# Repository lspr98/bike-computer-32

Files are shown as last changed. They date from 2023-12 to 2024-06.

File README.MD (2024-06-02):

# ESP32-based mini-map for biking

A simple mini-map based on an ESP32C3 for cycling. Renders a map based on the current position and optionally overlays a GPX-track. Featuring OSM-based offline maps with multi-constellation GNSS-positioning and GPX-track rendering.

**DISCLAIMER:** This is a hobby project which lacks documentation, clean code and unit tests.

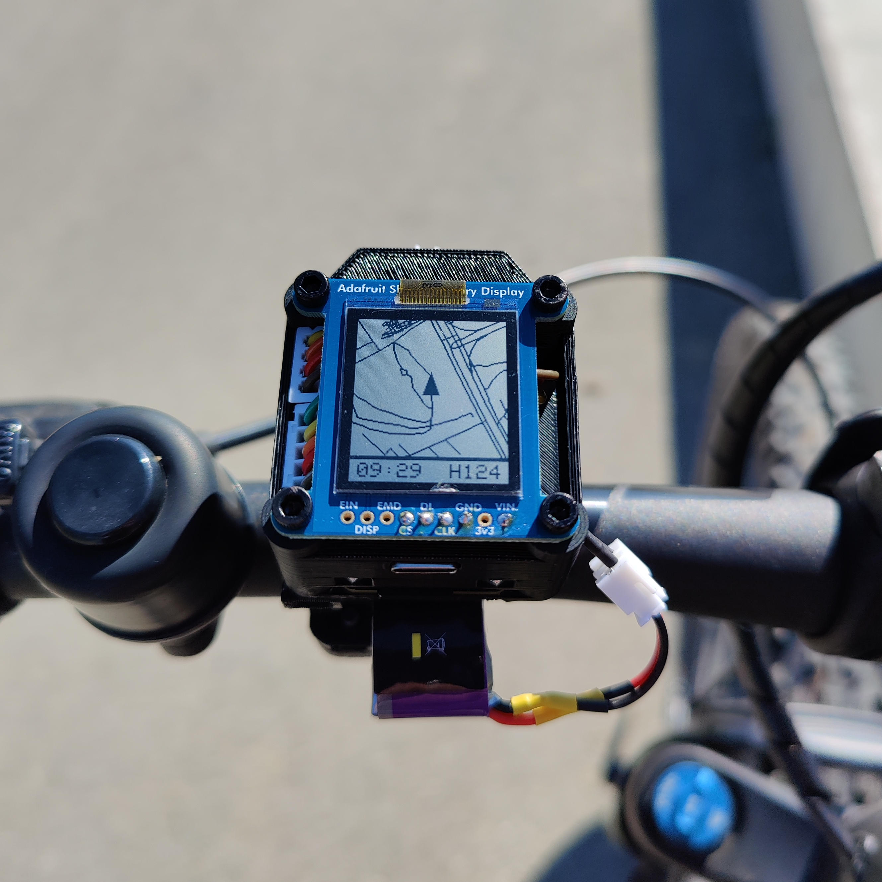
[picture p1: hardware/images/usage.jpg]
 


Even though the GIF is low-framerate, the ESP can easily render the map at 60 FPS if the currently shown part of the map isn't too busy.

The motivation behind this project was to create a cheap (~50€) device that displays a komoot gpx track as an overlay over a map for cycling. It has to work without a smartphone, be readable in direct sunlight and last a couple of hours in terms of battery.

## Project structure
```
hardware            Contains instructions/sources/files to build the physical device
software            Software to convert maps, view exported maps and the embedded code for the ESP
software/cpp        Tool to convert OSM maps to an optimized format for the ESP
software/python     Utilities to inspect converted maps and/or get familiar with the map layout
software/esp32      Firmware for the ESP32
```

## Building instructions
### Building the hardware
A wiring diagram, sourcing-list and a .STEP file of the whole assembly can be found in the **hardware** folder. Please refer to the STEP file for assembling the device.

For the 3D-Printed parts (**hardware/STL**), I recommend the following print settings:
|Settings|Value|
|---|---|
|Wall count|4|
|Top/Bottom Layers|4|
|Layer Height|0.2mm|
|Material|ABS/ASA|
|Infill|40%|
|Support|Yes|

My device is printed out of PLA+ but ASA/ABS is the better choice for this application.

### Creating a map
Follow the instructions in **software/cpp/README.MD** to compile the conversion tool and create a map binary.

### Preparing the SD-Card
1. Format the SD-Card as FAT32.
2. Place the map as **map.bin** in the root folder of the SD-Card
3. (Optional) Place the GPX-track as **track.gpx** in the root folder of the SD-Card

### Flashing the firmware
1. Install Visual Studio Code
2. Install the Platform.io extension for Visual Studio Code
3. Open the Platform.io project **software/esp32/esp32c3-bike-companion-32**
4. Have a look at the **main.cpp**. You may need to fix a bug in one of the libraries for the SDCard-Reader.
5. Connect your Seeed ESP32C3 to your PC
6. Flash the firmware

## Usage
All you need to do is mount the device to your bike and connect it to a power source.

The device will automatically power on. It does a small self check on boot and then enters fixing mode, where it remains until it receives a valid position fix from the GNSS module. The map with the current position is only rendered if there is a valid position fix, otherwise it will show "Fixing...".

## Troubleshooting
If the device encounters an issue during boot (e.g. one component shows **ER**), check the serial monitor for log messages.

## CAD Credits
The 3D-models for the ESP32C3 are from GrabCAD:

|Model|Author|Link|
|---|---|---|
|ESP32C3|[Maurice Pannard](https://grabcad.com/maurice.pannard-1)|[Source](https://grabcad.com/library/seeed-studio-xiao-esp32-c3-1)|

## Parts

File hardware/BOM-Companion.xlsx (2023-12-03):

Category | Description | Quantity | Price (€) | Sourcing
Fasteners | M2.5 x 8 FHCS | 2 | 0 | Local Hardware-Store / Screw Sortiment
 | M2.5 Nut | 2 | 0 | Local Hardware-Store / Screw Sortiment
 | M3 x 10 SHCS | 2 | 0 | Local Hardware-Store / Screw Sortiment
 | M3 x 30 SHCS | 4 | 0 | Local Hardware-Store / Screw Sortiment
 | M3 Nut | 6 | 0 | Local Hardware-Store / Screw Sortiment
Electronics | Seeed Xiao ESP32C3 | 1 | 4.55 | https://www.digikey.de/de/products/detail/seeed-technology-co-ltd/113991054/16652880
 | Adafruit Micro SD SPI/SDIO Card Breakout Board (Product ID: 4682) | 1 | 3.19 | https://www.digikey.de/de/products/detail/adafruit-industries-llc/4682/12822319
 | Adafruit SHARP Memory Display 1.3" 168x144 Monochrome (Product ID: 3502) | 1 | 22.75 | https://www.digikey.de/de/products/detail/adafruit-industries-llc/3502/7386264
 | Quectel L86-M33 | 1 | 11.38 | https://www.digikey.de/de/products/detail/quectel/L86-M33/13278361
 | MicroSD-Card | 1 | 5 | Electronics-Store / Amazon
 | LiPo 1s Battery 3.8V (Tiny-Whoop Battery) | 1 | 10 | Hobby-Shop / Amazon
 | Wires | ~1 meter | 0
 | Solder / Heatshrinks |  | 0
 | Plugs to connect components (optional) |  | 0
Misc | 3D-Printing Filament | ~50 gramms | 0
 | Double-Sided Tape |  | 0
Total |  |  | 56.87

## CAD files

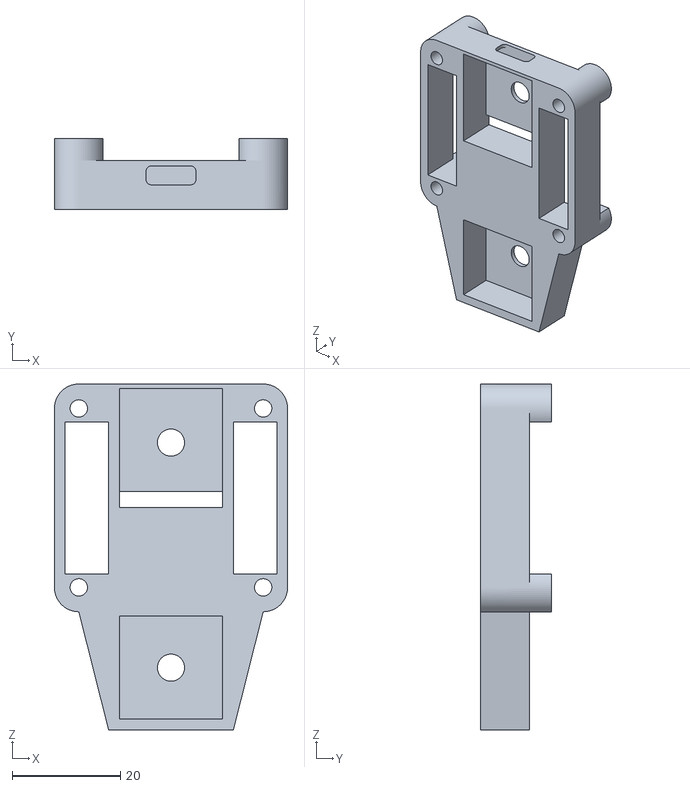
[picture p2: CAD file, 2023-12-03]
hardware/STL/MainFrameGNSSExposed v2.stl
43.0 x 13.0 x 63.8

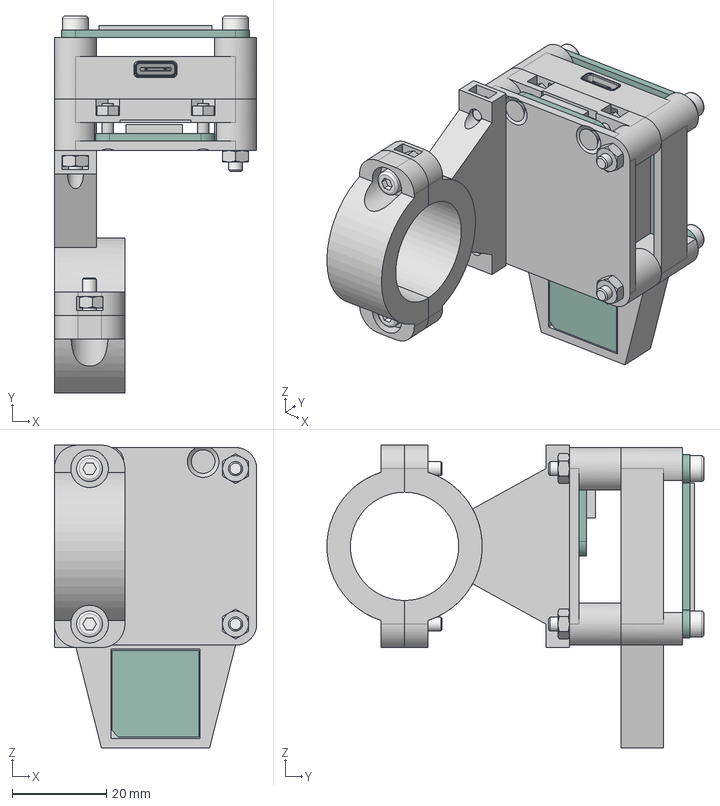
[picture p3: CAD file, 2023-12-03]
hardware/STEP/Bike-Companion-32.step
43.0 x 80.1 x 64.3 mm
M3x30 Screw x 4
M2_5x8 Screw x 2
M3x10 Screw x 2
Adafruit Sharp Memory Display
Adafruit SD-Card Reader
BOSS-EXTRUDE14_8_
BOSS-EXTRUDE7_4_
BOSS-EXTRUDE7_3_
BOSS-EXTRUDE14_4_
BOSS-EXTRUDE14_2_
BOSS-EXTRUDE14_11_
BOSS-EXTRUDE7_7_
BOSS-EXTRUDE14_9_
BOSS-EXTRUDE14_3_
BOSS-EXTRUDE14_7_
MIRROR2
BOSS-EXTRUDE14_5_
BOSS-EXTRUDE14_12_
BOSS-EXTRUDE7_8_
BOSS-EXTRUDE7_1_
BOSS-EXTRUDE14_10_
BOSS-EXTRUDE7_9_
BOSS-EXTRUDE14_6_
BOSS-EXTRUDE14_1_
BOSS-EXTRUDE7_6_
BOSS-EXTRUDE7_2_
CUT-EXTRUDE5
BOSS-EXTRUDE7_5_
U.FL Connector v1
Button (1) x 2
Shield
Quectel-L86
M2 Nut x 2
M3 Nut x 6
MainFrameGNSSExposed
BottomFrame
BikeMountUpper
BikeMountLower

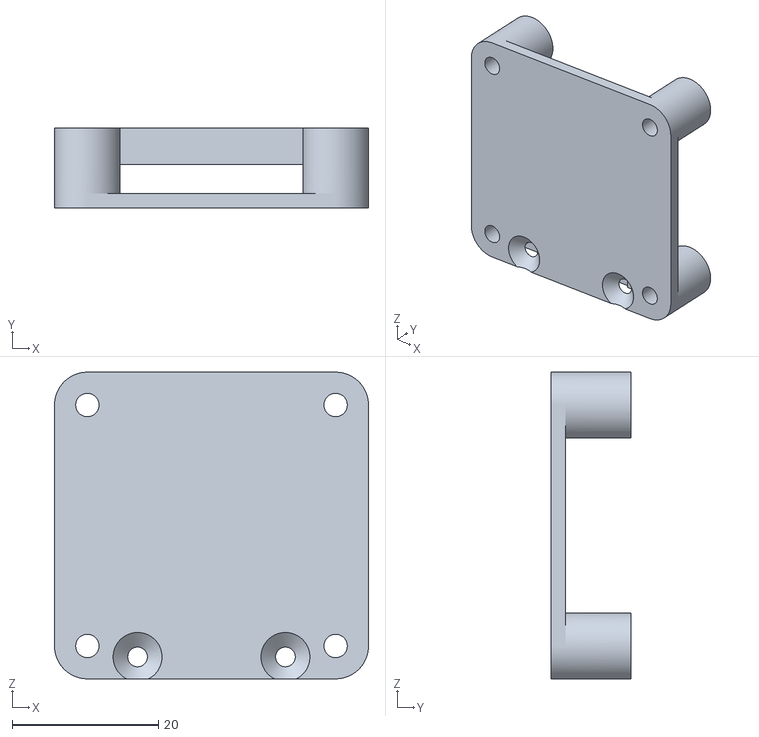
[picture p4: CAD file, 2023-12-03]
hardware/STL/BottomFrame v4.stl
43.0 x 11.0 x 42.0

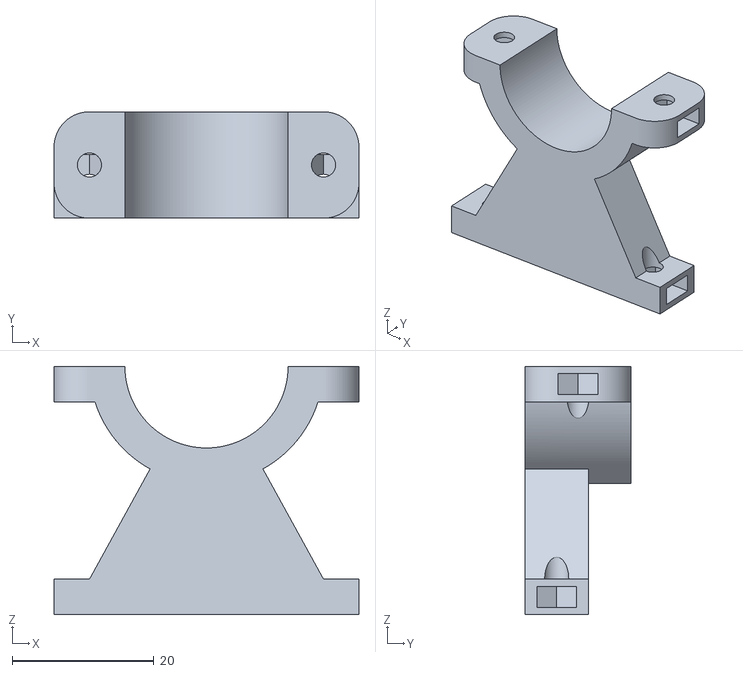
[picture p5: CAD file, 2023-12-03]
hardware/STL/BikeMountUpper v2.stl
43.0 x 15.0 x 35.0

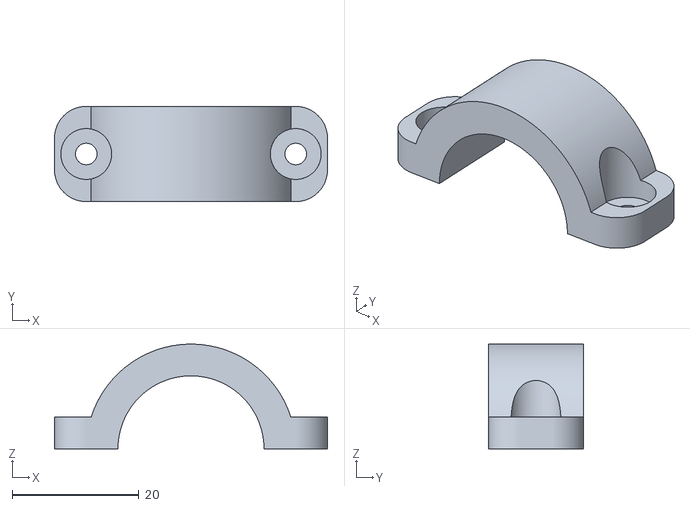
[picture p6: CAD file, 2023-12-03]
hardware/STL/BikeMountLower v1.stl
43.0 x 15.0 x 16.5

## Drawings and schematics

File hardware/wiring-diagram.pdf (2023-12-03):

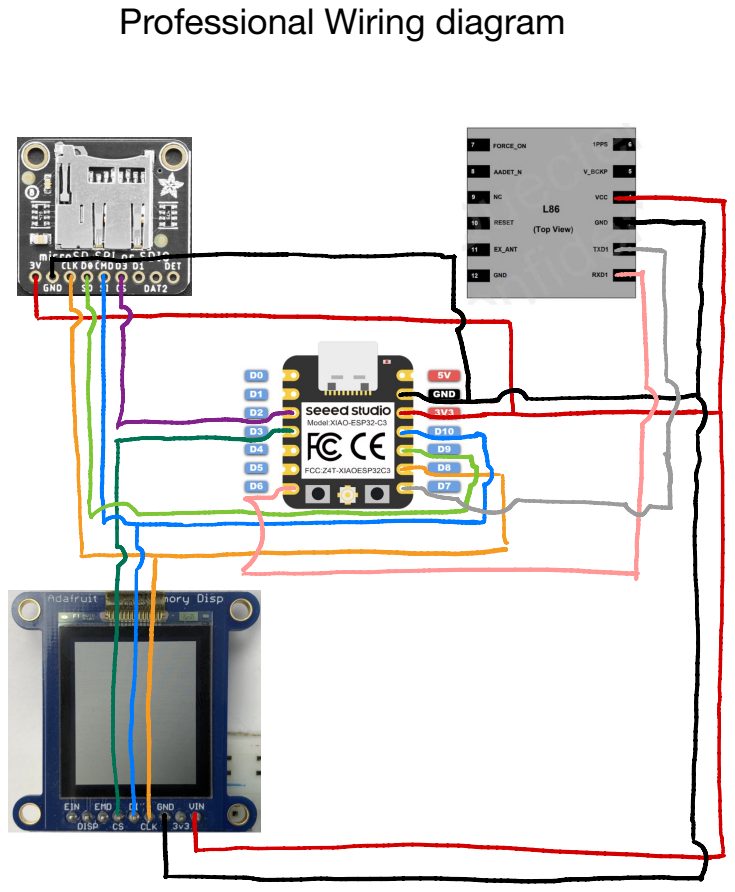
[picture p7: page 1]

Professional Wiring diagram

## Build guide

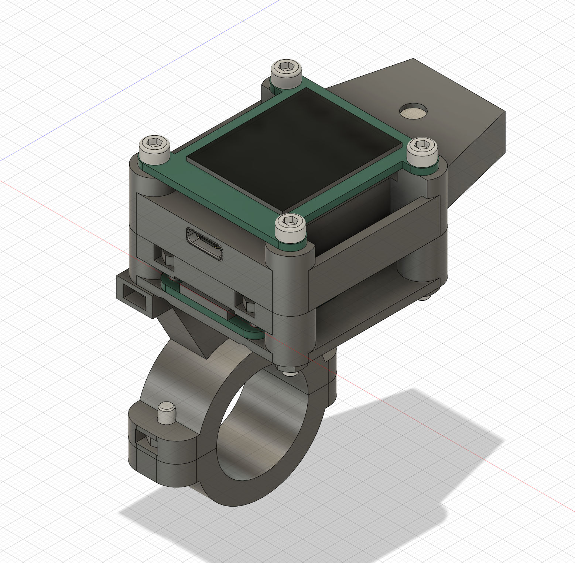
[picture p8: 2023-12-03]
hardware/images/assembly.jpg

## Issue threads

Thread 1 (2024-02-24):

Using an OLED display

korsehindi, 2024-02-24:
Hi,
The display used in this project is expensive and can't even be found in Chinese stores, how to use an 1.3 inch oled display with i2c connection.

lspr98, 2024-02-26:
Hey korsehindi,

the memory display was chosen due to its good readability in direct sunlight and low power consumption. Using an i2c display  (TFT, OLED, etc...) should be possible since the pins D4 and D5 are still unused but I cant guarantee it since I dont have any i2c displays to try it.

This repository provides some tests I wrote for the individual hardware components that you can adapt to make it work with your own display. Have a look at [software/esp32/esp32c3-display-test/src/main.cpp](https://github.com/lspr98/bike-computer-32/blob/main/software/esp32/esp32c3-display-test/src/main.cpp). The test renders a small part of a map to the display and rotates it indefinitely around the center. If you can use your display with the Adafruit GFX library, then it should be relatively straight forward to replace the display.* calls with the equivalent for your display.

Once that works, you can have a try at adapting [software/esp32/esp32c3-bike-companion-32/src/sharedspisdcard.cpp](https://github.com/lspr98/bike-computer-32/blob/main/software/esp32/esp32c3-bike-companion-32/src/sharedspidisplay.cpp) to your display but you will be on your own for that.

korsehindi, 2024-02-28:
Thanks, I will try, I hope I succeed.
I will probably need your help.

iDoka, 2024-04-02:
+1

Would be nice to have an alternative (and cheaper) display which can order on Aliexpress with at least several different suppliers.

If anybody know cheap E-Ink display with similar dimension - please share (sunlight is a huge issue in my geo).

idreamsi, 2024-04-02:
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

There is an alternative (and cheaper).
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

more info: [+](http://www.technoblogy.com/show?3YB0) , [+](https://www.aliexpress.com/item/1005003654720684.html)

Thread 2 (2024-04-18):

Segmentatio fault

cayleyflyer, 2024-04-18:
HI
Many thanks for sharing your code
I have compiled the code using cmake which all went well ,  but when i run it  "./osm2simpletile east.pbf  mapeast.bin"
it runs through process 1/6 and 2/6 and stops at 3/6

I get a segmentation fault at 3/6

**------------------------- 3/6 Mapping highways to tiles ------------------------
Segmentation fault (core dumped**)

I got the fault on my lap top which has 8mb of ram and also on my desktop machine. which is also running Ubuntu 22.04, with 32mb of ram. Any suggestions would be appreciated.
regards
jez

lspr98, 2024-04-19:
Hey jez,

I supposed you mean 8gb (or 32gb) of ram? Anyway, the segmentation fault is probably not due to insufficient RAM but rather a bug on my side. To help you, I would need two things from you:

1. Could you try it with a .osm.pbf file from [geofabrik](https://download.geofabrik.de/) ? Maybe they even offer the map that you are interested in. This is where I get my maps from and for example the [germany.osm.pbf](https://download.geofabrik.de/europe/germany-latest.osm.pbf) map conversion works fine for me.

2. Where did you get east.pbf from? I'd like to try it with your file too to see if I can reproduce the issue.

cayleyflyer, 2024-04-19:
HI,
Thank you for your reply ,

Yes sorry, 8gb on laptop 32gb on desktop!

And yes I got my map from geofabrik .The file is in England named "east-yorkshire-with-hull-latest.osm.pbf" i just shortened it to 'east.pbf'  so i did not have to keep typing a long name.

OK I ran a .pbf file from geofabrik  named "bremen-latest.osm.pbf" and it worked  OK and created a bin file . I downloaded a freash   "east-yorkshire-with-hull-latest.osm.pbf"  and it gives the Segmentation fault as described.

With the above result my feeling is,  because '0' degrees longitude runs through England (and actually my town )in East Yorkshire. Everything to the East of me has a positive Longitude number  and everything West of my town has a negative longitude number. Therefore when  I run the  osm2simpletile  on a map that crosses '0' degrees longitude it gives A Segmentation error.

could this be the issue, the code handing negative longitude and positive longitude in the same file?

Kind regards
jez

lspr98, 2024-04-20:
Hey Jez,

thanks for the hint with 0 longitude. The problem was indeed caused by negative longitude coordinates. I have updated the conversion tool, the python utilities and the esp firmware to support signed coordinates. Could you please pull again and let me know if it works for you?

There is still one catch though: the map may not render portions of streets when near the 0 longitude and/or 0 latitude mark. I'm unsure if this is caused by a bug or a design choice I made to reserve negative local tile coordinates to encode meta data later on. You can use the jupyter notebook test_plot_partial_map.ipynb to check it out for yourself.

cayleyflyer, 2024-04-20:
HI,
Thank you
Whatever you did has solved the issue and now the OSM.pbf files that bisect '0' degrees lon,  compile to a .bin file OK.
For my flight instrument project I am aim to create a custom map showing Airspace restrictions with just main roads, railway lines and major landmarks, which can be seen from the air. so small streets will not be an issue.

many thanks for you help

Kind regards
Jez

Closed 2024-04-20.

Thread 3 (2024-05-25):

map scale

cayleyflyer, 2024-05-25:
Hi,
I am using a 400 x 240 Sharp Memory LCD. I am trying to fill the screen with a map to show a larger area. I can change the RENDER_TILES_PER_DIM = 7 and DETAULT_ZOOM_LEVEL = 0.1 (in Globalconfig.h). this produces a map of the scale close to what I wish to have (see pic)
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

The map however does not fill the screen,  and  7 appears to be the max number I can  use in RENDER_TILES_PER_DIM.  If I enter 9 or 11 for example it will not render the tiles. I thought it may be due to the tile renderer buffer size. I noted the buffer size in tileblockrederer.cpp (_renderTileData = new int16_t[_perTileBufferSize * N_RENDER_TILES])  was an int16_t so I changed it to a int32_t but this had no effect.

Have you any ideas that could allow me zoom out and fill the screen to see more area. For my project  I need to see at least 6km in front of my GPS position and 2km each side of my GPS position.

kind regards
Jeremy

lspr98, 2024-05-26:
Hey Jeremy,

my guess is that you are running out of RAM, which is why the map stops rendering if you go too high with **RENDER_TILES_PER_DIM**. From your picture, I see that you are using an ESP-WROOM-32, which comes with 520 kb of SRAM according to its datasheet. The size for **_renderTileData** is calculated based on the maximum number of nodes across all tiles in the map (**max_nodes** in header) and the number of tiles that are rendered (**N_RENDER_TILES**). The DACH map I am using has 4405 max_nodes, which means a 3 by 3 tile buffer requires 4405 * 2 * 3 * 3 ~ 80kb of RAM. A 7 by 7 buffer already requires ~431kb and a 9 by 9 buffer would require ~713kb, which exceeds that if your board. You can check the **max_nodes** value using the jupyter notebook **test_loading.ipynb** by printing the header dict after loading (in python, the value is called **max_tile_nodes**).

The simplest solution would be to upgrade to an ESP with more RAM, but I do not recommend that, since the computational complexity for rendering the map rapidly increases for a large amount of tiles. If you are moving fast, it will also constantly have to reload a lot of tiles from the SD-Card, which creates stutter.

As an alternative, you could change the **tile_size** in **main.cpp** of the map conversion tool to a higher value, say 1024 (or higher) instead of 512. This will have the same effect as zooming out with a factor of 2. A **DETAULT_ZOOM_LEVEL = 1.0** means that the tile matches the display width defined in **DISPLAY_WIDTH**. To resolve the RAM issue, you will have to refine the filter in the map conversion tool (search for all occurances of "highway" in **CustomHandlers.hpp**), to exclude smaller ways and only keep major highways, which will reduce the maximum number of nodes on the tiles. For the zoom level that you request (6 by 2 km map on a 400 x 240 screen) this shouldn't really be an issue.

Also note that **Globalconfig.h** has two constants **DISPLAY_WIDTH** and **DISPLAY_HEIGHT** that you will need to adapt.

Just out of curiosity, does it render across the full screen when you set **DETAULT_ZOOM_LEVEL = 1.0** with **RENDER_TILES_PER_DIM = 7** ? Maybe there is also another issue with different screen aspect ratios.

cayleyflyer, 2024-05-28:
Hi,
Thank you,
You detailed reply has made me better understand the code.

Yes the the map did render across the full sceen at Zoom level 1, however that map tile was size 513 nodes*2*7*7 = 50kb. My initial statergy was wrong, in trying to reduce the zoom size and increase the number of tiles to get the  6km x 4km view, as you have kindly explained in your reply. Increasing tile size will work.

After testing last night I created several maps at 1024,1800,1900,2048 tile size. I set zoom =1 and DIM = 3 .
max_nodes in each which gave 9kb,26kb,55,kb,64kb,72kb. However only maps upto (1800) 55kb loaded and displayed correctly. I will need a tile size 4096 to achieve the zoom level I need. With the ESP's 512kb of memory it should load with ease but mine does not. I have ordered a new ESP32 to rule out hardware issues, and I will make sure I have not mistakenly altered some code when adapting it to work without the shared SPI on the Wroom Board.

Again many thanks for your help
kind regards
Jeremy

thankyou for you help i am sure I will get

cayleyflyer, 2024-05-30:
A new ESP made no difference. So I kept the map tile size to 4096 in main.cpp and I filtered the large pbf file using OSMIUM to remove residential streets which reduced the max_nodes like this ,,,,, osmium tags-filter my.osm.pbf w/natural=water w/railway = rail w/railway=abandoned w/highway=motorway w/highway=trunk w/highway=primary w/highway=secondary w/highway=tertiary w/highway=unclassified  \-o reduced_node .pbf

This created a a map file  showing an area of 5.5km x 3.5km at zoom=1 and DIM=3 and kept the buffer to 38kb.
regards
Jeremy

lspr98, 2024-06-02:
Hey Jeremy,

sorry for the delay. I did some tests with my ESP and have to admit a mistake in the formula for calculating the necessary memory, there is a factor of 2 missing, since each node consists of two 16bit signed integers (which means 4 bytes per node are required). The **_renderTileData** buffer is initialized via heap initialization, so it is possible to check the memory before and afterwards via `ESP.getFreeHeap()`. Here is the header of the map I'm using as read by the jupyter notebooks provided:
```
{
'map_x': 652675,
'map_y': 5982838,
'map_width': 1027954,
'map_height': 1390019,
'n_x_tiles': 2008,
'tile_size': 512,
'n_tiles': 5451720,
'max_tile_nodes': 2871,
'total_tile_nodes': 104140822,
'ways': 64903320
}
```

Calling the method mentioned above allows you to print out the available heap memory for the buffer before and after buffer allocation. I wrote some debug messages to check how much memory is actually allocated:
```
maxNodes: 2871, nRenderTiles: 9, perTileBufferSize: 5742, sizeof(int16_t): 2
Free heap before _renderTileData allocation: 265564 bytes
_renderTileData size: 103356 bytes
Free heap after _renderTileData allocation: 162192 bytes
```
So **max_nodes** * **N_RENDER_TILES** * **sizeof(int16_t)** * 2 is the actual size required in bytes. In my case, that is ~100kb for a 3x3 tile layout.

That means rendering a 5x5 tile layout is already out of scope:
```
maxNodes: 2871, nRenderTiles: 25, perTileBufferSize: 5742, sizeof(int16_t): 2
Free heap before _renderTileData allocation: 265308 bytes
_renderTileData size: 287100 bytes
# CRASH
```

The available heap can vary from board to board and also depends on the GPX track size if you are using that feature. I hope that helps clarify the memory issue. Still, changing the tile size and filtering out smaller streets is in my opinion the best solution. I interpret your last message that you were able to achieve your goal with the new filter? If so, please feel free to close the issue. Also, a picture of your bigger display rendering the map would be appreciated :)

cayleyflyer, 2024-06-03:
hi,
on holiday back saturday so will post screen pic

Closed 2024-06-08.

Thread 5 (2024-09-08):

printing waypoint and place names

cayleyflyer, 2024-09-08:
`HI,`
I have managed to make an airspace map covering the whole of the uk at a scale of 3km x 5km on the screen at zoom level 1. I  have altered the GPXtrack entry to include a waypoint name. example trkpt lat="53.901000" lon="-0.171614" name= "wp1" . I can now display the points on the map. I also have  the coordinates of all uk towns and villages so I can show them on the map.

I am however having difficulty  printing the name from the GPX file on the screen next to the waypoint.

I believe the TileBlockRenderer.cpp  and SharedSPISDCard.cpp are the blocks of code that read and render the GPXfile.
From within the function/method named void TileBlockRenderer::renderGPX(LocalGeoPosition& center). I have tried to use  _display->write1 () with some success (i copied display.write it and changed its paramiters to 'char'. In doing so I can  print  on the screen,but only one letter of the waypoint array (see picture below).  I am having difficulty in finding a way to get all the characters in the waypoint name into one array and to print it on the screen. I can create  a char*wplist for each letter in the name and do it that way but that seems wrong to me to do that.

 the altered the GPXtrack.h as below to include a variable to hold the waypoint name letters.
/*
    GPX-Track
*/
struct GPXTrack {
public:
    int16_t* xList;
    int16_t* yList;
    char* wplist; //char* wplist works,  char*wplist[8] and char wplist does not work
    char* wplist1; //char* wplist1 works,  char*wplist[8] and char wplist does not work
    char* wplist2; //char* wplist2 works,  char*wplist[8] and char wplist does not work
    uint64_t* tileIdList;
    uint32_t numNodes;
    uint32_t nearestNodeId;
};

inside this code block:-
bool SharedSPISDCard::readGPX(SimpleTile::Header& header, GPXTrack& track) {

I have added
  // Allocate memory for track data for each letter in name
track.wplist = new char[n_nodes]; // not sure if this makes any difference
track.wplist1 = new char[n_nodes]; // not sure if this makes any difference
track.wplist2 = new char[n_nodes]; // not sure if this makes any difference

I have added,  ptr_wp_start and ptr_wp_end routines which follow the format for lat and lon routines including, ptr_wp_start = line.indexOf("name") + 6; to extract the waypoint name.

I have converted the waypoint String from above to a null terminated char array called 'wpo' using toCharArray()
   
below is an extract from the serial monitor showing I have successfully parsed the GPXfile and placed the waypoint name into a char array called 'wpo'
      sout << " lat " << lat <= "  ";
      sout << " lon " << lon <= "  ";
      sout << "name " << wpo <= " ";    )

Free heap before GPX: 296656
Free heap after GPX: 296512
 lat 53.90
 lon -0.17
name ap1
 lat 53.91
 lon -0.17
name bp2

I only seem to able to pass one letter in the waypoint into _track.wplist[i]
In tileblockrenderer.cpp, therefore I have added a line for each letter in wp name which works!.
         char wp = _track->wplist[nidx];
         char wp1 = _track->wplist1[nidx];
         char wp2 = _track->wplist2[nidx];

I have using this method successfully printed the waypoint name on the screen next to the waypoint marker, but I have been unable to concaternate all the letters into one array and print the full name. So an 8 letter name required 8 lines of code

I think I am missing some knowledge, about how to pass the whole waypoint name in one variable and into the 'wplist' and print it.

Any advice on how I could achieve printing the name to the screen  would be welcome. ?

kind regards
Jeremy

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

lspr98, 2024-09-28:
Hey Jeremy,

if I understand your issue correctly, you are trying to provide waypoint names through the GPX file and display them on the screen. I am unsure what exactly which changes you made in the code and to help you resolve your issue it would be great if you could post your code changes as a public fork of this repository, so I can have a look at it.

I tried to sketch some code sketch for you with the way I interpret how you are trying to solve the problem. It is a sketch though, no guarantee if it works, I haven't tested it:

1. Extend the GPXTrack with a new field `nameList` which will hold all waypoint names.
```
struct GPXTrack {
public:
    int16_t* xList;
    int16_t* yList;
    char** nameList;
    uint64_t* tileIdList;
    uint32_t numNodes;
    uint32_t nearestNodeId;
};
```
Note that `nameList` is a "pointer to a pointer", since we need a 2D `char` array to hold the chars for each name for each waypoint.

2. In `SharedSPISDCard::readGPX` after the first pass through the GPX file, we know the number of waypoints (`n_nodes`) which we can use to allocate the first dimension of the `nameList`:
```
track.tileIdList = new uint64_t[n_nodes];
track.xList = new int16_t[n_nodes];
track.yList = new int16_t[n_nodes];
track.nameList = new char*[n_nodes];
```
Again, `nameList` is an array of `char*`, each element of `nameList` will point to the first character of a waypoint name.

3. In `SharedSPISDCard::readGPX` during the second pass through the GPX file, find the start and end pointers to the waypoint name:
```
ptr_name_start = line.indexOf("name") + 6;
ptr_name_end = ptr_name_start;
while(line.c_str()[ptr_name_start] != '\"') {
    ptr_name_end++;
    if(ptr_name_end == line.length()) {
        sout.err() <= "Failed to read NAME for GPX track";
        return false;
    }
}
```
`ptr_name_start` will be the character offset to the first waypoint name character, while `ptr_name_end` will be the offset to the last waypoint name character.

4. In `SharedSPISDCard::readGPX`, allocate space for the current waypoint name and copy it from the GPX-file string:
```
uint16_t nameLength = ptr_name_end - ptr_name_start;
// Allocate space for the i-th waypoint name. We need one additional character for null-termination
track.nameList[i] = new char[nameLength + 1];
memcpy(track.nameList[i], &(line.c_str()[ptr_name_start]), nameLength * sizeof(char));
// Add null termination at end of waypoint name
track.nameList[i][nameLength + 1] = '\0';
```

After that, `track.nameList[i]` gives you the i-th null-terminated waypoint name, which you can pass to your function for showing the names on the display.

I am however not planning on implementing this feature, so you will be on your own for that.

cayleyflyer, 2024-09-28:
many thanks,
that has worked.
I have a bit to learn about pointers.
kind regards
jeremy

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

cayleyflyer, 2024-09-28:
thanks

Closed 2024-09-28.

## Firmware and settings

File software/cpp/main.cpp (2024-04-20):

#include <iostream>
#include <fstream>
#include <ostream>
#include <osmium/visitor.hpp>
#include <osmium/io/any_input.hpp>
#include <osmium/handler.hpp>
#include <osmium/util/memory.hpp>
#include <osmium/osm/location.hpp>
#include <osmium/geom/mercator_projection.hpp>
#include <osmium/geom/tile.hpp>
#include <osmium/index/map/flex_mem.hpp>
#include <osmium/handler/node_locations_for_ways.hpp>

#include <BoundingBox.hpp>
#include <Tile.hpp>
#include <CustomHandlers.hpp>

using index_type = osmium::index::map::FlexMem<osmium::unsigned_object_id_type, osmium::Location>;
using location_handler_type = osmium::handler::NodeLocationsForWays<index_type>;



int main(int argc, char *argv[]) {

    if (argc != 3) {
        std::cout << "Usage: osm2simpletile PATH_TO_INPUT_FILE PATH_TO_OUTPUT_FILE \n";
        return 1;
    }

    // Tile size (in mercator coordinates)
    int tile_size = 512;

    // Map statistics
    double map_height, map_width;
    int n_x_tiles, n_y_tiles, n_tiles, n_collisions, map_x, map_y, max_way_node_count, n_ways, n_undefined, max_tile_nodes, all_way_node_count;
    long total_tile_nodes, total_filesize;
    uint64_t highways;

    // Buffers for calculating sizes
    int byte_header, byte_ptr, byte_tiles;
    uint16_t* nodes_per_tile;
    uint16_t* byte_per_tile;
    uint64_t* ptr_per_tile;

    // Buffers to store coordinates and IDs
    int32_t* node_x_coords;
    int32_t* node_y_coords;
    uint64_t* highway_indices;

    // Read OSM input file
    const osmium::io::File input_file{argv[1]};

    // Create node location index and apply box handler to get bounding boxes for all ways
    index_type index;
    location_handler_type location_handler{index};

    // First pass. Generate statistics.
    std::cout << "------------------------- 1/6 Gathering map statistics -------------------------\n";
    osmium::io::Reader reader{input_file, osmium::osm_entity_bits::node | osmium::osm_entity_bits::way};
    StatHandler stats;
    osmium::apply(reader, location_handler, stats);
    reader.close();

    map_height = stats.max_y-stats.min_y;
    map_width = stats.max_x-stats.min_x;
    n_x_tiles = ceil(map_width/tile_size);
    n_y_tiles = ceil(map_height/tile_size);
    n_tiles = n_x_tiles*n_y_tiles;
    all_way_node_count = stats.all_way_node_count;
    map_x = stats.min_x;
    map_y = stats.min_y;
    highways = stats.highways;
    max_way_node_count = stats.max_way_node_count;
    n_ways = stats.ways;

    stats.printStatistics();
    location_handler.clear();
    std::cout << "X-tiles: \t\t\t" << n_x_tiles << "\n";
    std::cout << "Y-tiles: \t\t\t" << n_y_tiles << "\n";
    std::cout << "Total tiles: \t\t\t" << n_tiles << "\n";

    // Create array to hold bounding boxes for all ways
    WayBox* wBoxes = new WayBox[highways];

    // Second pass. Get collisions between tiles and highways
    std::cout << "---------------------------- 2/6 Finding collisions ----------------------------\n";
    BoxHandler bHandler(wBoxes, tile_size, n_x_tiles, map_x, map_y);
    osmium::io::Reader reader2{input_file, osmium::osm_entity_bits::node | osmium::osm_entity_bits::way};
    osmium::apply(reader2, location_handler, bHandler);
    reader2.close();

    n_collisions = bHandler.n_collisions;
    n_undefined = bHandler.n_undefined;

    location_handler.clear();

    std::cout << "all_way_node_count: \t\t" << all_way_node_count << "\n";
    std::cout << "Collisions: \t\t\t" << n_collisions << "\n";
    std::cout << "Undefined bboxes: \t\t" << n_undefined << "\n";


    // Third pass. Generate mapping between tiles and highways
    std::cout << "------------------------- 3/6 Mapping highways to tiles ------------------------\n";
    nodes_per_tile = new uint16_t[n_tiles] {0};
    osmium::io::Reader reader3{input_file, osmium::osm_entity_bits::node | osmium::osm_entity_bits::way};
    TileAssigner tHandler(n_collisions, tile_size, n_x_tiles, map_x, map_y, max_way_node_count, wBoxes, nodes_per_tile);
    osmium::apply(reader3, location_handler, tHandler);
    reader3.close();
    total_tile_nodes = tHandler.total_number_of_tile_nodes;
    location_handler.clear();

    // Fourth pass. Get all mercator coordinates of all highways
    std::cout << "-------------------------- 4/6 Converting coordinates --------------------------\n";
    node_x_coords = new int32_t[all_way_node_count];
    node_y_coords = new int32_t[all_way_node_count];
    highway_indices = new uint64_t[highways];
    osmium::io::Reader reader4{input_file, osmium::osm_entity_bits::node | osmium::osm_entity_bits::way};
    MercatorConverter mercConv(node_x_coords, node_y_coords, highway_indices);
    osmium::apply(reader4, location_handler, mercConv);
    reader4.close();
    location_handler.clear();


    std::cout << "--------------------- 5/6 Calculating storage requirements ---------------------\n";
    byte_per_tile = new uint16_t[n_tiles];
    ptr_per_tile = new uint64_t[n_tiles];

    // The header stores the following metadata:
    //  map_x       uint64  x-coordinate of lower left corner (mercator-web)
    //  map_y       uint64  y-coordinate of lower left corner (mercator-web)
    //  map_width   uint64
    //  map_height  uint64
    //  n_x_tiles   uint64  number of tiles in x direction
    //  tile_size   uint64  size of tile
    //  n_tiles     uint64  number of tiles
    //  max_nodes   uint64  largest number of nodes on single tile
    //  n_nodes     uint64  number of nodes
    //  n_ways      uint64  number of ways

    byte_header = 10*8;
    byte_ptr = 0;
    byte_tiles = 0;
    max_tile_nodes = -1;

    for(int i=0; i<n_tiles; i++) {
        if(nodes_per_tile[i] > max_tile_nodes) {
            max_tile_nodes = nodes_per_tile[i];
        }
        if(i==0) {
            ptr_per_tile[i] = 0;
        } else {
            ptr_per_tile[i] = ptr_per_tile[i-1] + byte_per_tile[i-1];
        }
        // Store size of current tile and allocate memory
        byte_per_tile[i] = 2*sizeof(uint16_t)*nodes_per_tile[i];

        // Add space needed for node locations and delimiters
        byte_tiles += byte_per_tile[i];
        // Add space needed for tile-pointer (64-bit pointer -> 8 byte)
        byte_ptr += 8;
    }

    delete byte_per_tile;
    delete nodes_per_tile;

    total_filesize = byte_header + byte_ptr + byte_tiles;

    std::cout << "Filesize total: \t\t" 
        << (total_filesize/(1000)) << "KB ~= " 
        << (total_filesize/(1000*1000)) << "MB ~= " 
        << (total_filesize/(1000*1000*1000)) << "GB\n";

    std::cout << "File composition: \t\t"
        << (int)(((float)byte_header/total_filesize)*100) << "% Header, "
        << (int)(((float)byte_ptr/total_filesize)*100) << "% Pointer, "
        << (int)(((float)byte_tiles/total_filesize)*100) << "% Tiles \n";


    
    std::cout << "------------------------------- 6/6 Writing map --------------------------------\n";
    // Finally, create the output file!
    // Create buffer for nodes
    uint64_t* buffer_header = (uint64_t*) new char[byte_header];
    // buffer_pointer has tile offsets in BYTE count
    uint64_t* buffer_pointer = ptr_per_tile;
    // buffer_tiles has the buffer data
    int16_t* buffer_tiles = (int16_t*) calloc(byte_tiles, sizeof(char));
    // Write header buffer
    //  map_x       uint64  x-coordinate of lower left corner (mercator-web)
    //  map_y       uint64  y-coordinate of lower left corner (mercator-web)
    //  map_width   uint64
    //  map_height  uint64
    //  n_x_tiles   uint64  number of tiles in x direction
    //  tile_size   uint64  size of tile
    //  n_tiles     uint64  number of tiles
    //  max_nodes   uint64  largest number of nodes on single tile
    //  n_nodes     uint64  number of nodes, including separators
    //  n_ways      uint64  number of ways
    buffer_header[0] = (int64_t) map_x;
    buffer_header[1] = (int64_t) map_y;
    buffer_header[2] = (uint64_t) map_width;
    buffer_header[3] = (uint64_t) map_height;
    buffer_header[4] = (uint64_t) n_x_tiles;
    buffer_header[5] = (uint64_t) tile_size;
    buffer_header[6] = (uint64_t) n_tiles;
    buffer_header[7] = (uint64_t) max_tile_nodes;
    buffer_header[8] = (uint64_t) total_tile_nodes;
    buffer_header[9] = (uint64_t) n_ways;

    int* idx_arr;
    Tile currTile;

    // Write tile buffer
    uint64_t* _local_pointer_offsets = (uint64_t*) calloc(n_tiles, sizeof(uint64_t));

    for(uint64_t hw_id=0; hw_id < highways; hw_id++) {
        // Get bounding box of current way
        auto curr_wBox = wBoxes[hw_id];
        // Get number of colliding tiles
        int n_idx_curr = curr_wBox.get_n_colliding_tiles(tile_size, n_x_tiles, map_x, map_y);
        // Allocate memory for tile indices
        idx_arr = new int[n_idx_curr];
        // Get colliding tile indices
        curr_wBox.get_colliding_tiles(tile_size, n_x_tiles, map_x, map_y, idx_arr);
        // idx_arr now contains the indices for all colliding tiles.

        // Find containing nodes for each colliding tile

        // ANY CHANGE TO THIS LOGIC HAS TO BE REPLICATED IN THE TILEASSINGER!
        // TODO: Make this better, it is horrible
        for(int i=0; i<n_idx_curr; i++) {
            // Create tile
            int curr_tile_id = idx_arr[i];
            currTile = Tile(curr_tile_id, tile_size, n_x_tiles, map_x, map_y);
            // J goes over all nodes for current hw!
            uint64_t j_end = 0;
            // Last highway.
            if(hw_id == highways-1) {
                j_end = all_way_node_count-1;
            } else {
                j_end = highway_indices[hw_id+1];
            }

            bool prev_node_in_tile = false;

            for(uint64_t j=highway_indices[hw_id]; j<j_end; j++) {
                if(currTile.contains(node_x_coords[j], node_y_coords[j])) {
                    // I=tile_idx
                    // J=node_idx
                    // Check if we need to add the previous node too
                    if(!prev_node_in_tile && j > highway_indices[hw_id]) {
                        if(currTile.isSouthWestOf(node_x_coords[j-1], node_y_coords[j-1])) {
                            // Add previous node.
                            currTile.write_global_coord(
                                node_x_coords[j-1],
                                node_y_coords[j-1],
                                buffer_tiles + (buffer_pointer[curr_tile_id] + _local_pointer_offsets[curr_tile_id])/2
                            );
                            // Increase local pointer offset
                            _local_pointer_offsets[curr_tile_id] += 2*sizeof(int16_t);
                        }
                    }
                    // Add current node in buffer for I-th tile
                    currTile.write_global_coord(
                        node_x_coords[j],
                        node_y_coords[j],
                        buffer_tiles + (buffer_pointer[curr_tile_id] + _local_pointer_offsets[curr_tile_id])/2
                    );
                    // This operation always writes two coordinates, so we increase the pointer offset by 2*sizeof(int16_t)
                    _local_pointer_offsets[curr_tile_id] += 2*sizeof(int16_t);
                    // Write separator if way ends.
                    if(j==j_end-1) {
                        currTile.write_way_separator(buffer_tiles + (buffer_pointer[curr_tile_id] + _local_pointer_offsets[curr_tile_id])/2);
                        _local_pointer_offsets[curr_tile_id] += 2*sizeof(int16_t);
                    }
                    // Signal that tile was added
                    prev_node_in_tile = true;
                } else {
                    // Current node is not in tile.
                    if(prev_node_in_tile && currTile.isSouthWestOf(node_x_coords[j], node_y_coords[j])) {
                        // Add the one node that was to the top right of tile
                        currTile.write_global_coord(
                            node_x_coords[j],
                            node_y_coords[j],
                            buffer_tiles + (buffer_pointer[curr_tile_id] + _local_pointer_offsets[curr_tile_id])/2
                        );
                        // This operation always writes two coordinates, so we increase the pointer offset by 2*sizeof(int16_t)
                        _local_pointer_offsets[curr_tile_id] += 2*sizeof(int16_t);
                    }
                    if(prev_node_in_tile || j==j_end-1) {
                        // Write separator if end of way.
                        currTile.write_way_separator(buffer_tiles + (buffer_pointer[curr_tile_id] + _local_pointer_offsets[curr_tile_id])/2);
                        _local_pointer_offsets[curr_tile_id] += 2*sizeof(int16_t);
                    }
                    prev_node_in_tile = false;
                }
            }
        }

        // Avoid memory leak
        delete idx_arr;
    }

    FILE* file = fopen(argv[2], "wb");
    fwrite(buffer_header, sizeof(buffer_header[0]), 10, file);
    fwrite(buffer_pointer, sizeof(buffer_pointer[0]), n_tiles, file);
    fwrite(buffer_tiles, sizeof(buffer_tiles[0]), byte_tiles/sizeof(buffer_tiles[0]), file);
    fclose(file);

    std::cout << "Map created successfully at: " << argv[2] << "\n";

}

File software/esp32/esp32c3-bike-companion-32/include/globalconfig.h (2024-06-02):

#ifndef _GLOBALCONFIG_H
#define _GLOBALCONFIG_H

/**
 * 
 *  Configuration file for the companion.
 * 
**/

/**
 * 
 *      SPI Configuration
 * 
**/
#define SPI_FREQ 8000000
#define DISPLAY_CS  D3
#define SDCARD_CS   D2

/**
 * 
 *      GNSS module
 * 
**/
#define GNSS_BAUD   115200
#define GNSS_ENABLE_MULTI_CONSTELLATION true
#define GNSS_ENABLE_LOW_POWER false
#define GNSS_ENABLE_HIGH_REFRESH false
#define GNSS_MIN_UPDATE_TIME_MS 1000

/**
 * 
 *      Display module
 * 
**/
#define BLACK 0
#define WHITE 1

#define DISPLAY_WIDTH 144
#define DISPLAY_HEIGHT 168
#define POSITION_MARKER_SIZE 8


/**
 * 
 *      Geographic utilities
 * 
**/

// Radius of the earth.
#define R_EARTH 6378137.0

/**
 * 
 *      Map Rendering
 * 
**/

// Default map zoom level. 1.0 means that exactly one tile fits on the display.
#define DETAULT_ZOOM_LEVEL 1.25

// Number of tiles per dimension to keep in memory. Must be an uneven number > 1
#define RENDER_TILES_PER_DIM 3

// If the map should be rotated to be alinged with heading.
#define RENDER_HEADING true

// Minimum time between two consecutive tile data updates in milliseconds.
#define TILE_UPDATE_DEBOUNCE_MS 5000

// Minimum free heap memory required after tile buffer allocation
#define MIN_FREE_HEAP 10000


/**
 * 
 *      Settings for UI
 * 
**/
#define TARGET_FPS 60

#define BOOTSCREEN_SPINNER_SIZE 10
#define BOOTSCREEN_TEXT_SIZE 2

// Statusbar
// Number of characters per stat in the status bar, including terminator
#define N_CHAR_PER_STAT 6
// Status bar element codes:
// 0 = time
// 1 = date
// 2 = speed
// 3 = heading
// 4 = lat
// 5 = lon
// 6 = nsats
// Left element of status bar
#define LEFT_STAT 0
// Right element of status bar
#define RIGHT_STAT 3




/**
 * 
 * Derived globals (DO NOT CHANGE)
 * 
**/

#define TARGET_FRAME_TIME_MS 1000/TARGET_FPS

#define DISPLAY_MAX_DIM sqrt(DISPLAY_WIDTH*DISPLAY_WIDTH/2)
#define DISPLAY_WIDTH_HALF DISPLAY_WIDTH/2
#define DISPLAY_HEIGHT_HALF DISPLAY_HEIGHT/2

#define RENDER_TILES_PER_DIM_HALF RENDER_TILES_PER_DIM / 2
#define N_RENDER_TILES RENDER_TILES_PER_DIM*RENDER_TILES_PER_DIM

#endif

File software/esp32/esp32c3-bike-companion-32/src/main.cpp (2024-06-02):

#include <Arduino.h>
#include <FS.h>
#include <SD.h>
#include <SPI.h>
#include <MicroNMEA.h>
#include <Adafruit_GFX.h>
#include <Adafruit_SharpMem.h>

#include <gnssmodule.h>
#include <sharedspisdcard.h>
#include <sharedspidisplay.h>
#include <sharedspimutex.h>
#include <simpletile.h>
#include <constgeoposition.h>
#include <tileblockrenderer.h>
#include <uirenderer.h>
#include <serialutils.h>
#include <globalconfig.h>
#include <interppositionprovider.h>

/*

    IMPORTANT:  There is a bug in sd_diskio that causes a "Check status failed" if the SDCard-Reader
                and other SPI devices are hooked up to the same SPI bus. See the following github
                issue on how to fix this: https://github.com/espressif/arduino-esp32/issues/8534

                If you do not adapt the ff_sd_status method in sd_diskio accordingly, you will get an error.

*/


// Header of bin map file
SimpleTile::Header header;

uint16_t currHeading = 0;

// Fixed position provider for debugging
GeoPosition currPos(48.136223, 11.594579);
ConstGeoPosition mockPosProvider(currPos, currHeading);

SharedSPIDisplay display(DISPLAY_CS);
SharedSPISDCard sdcard(SDCARD_CS);
GNSSModule gnss(0);
GPXTrack track;

InterpPositionProvider ipos(&gnss, ((float) GNSS_MIN_UPDATE_TIME_MS) / ((float) TARGET_FRAME_TIME_MS));

// Path to map-file on SD-card
const char binary_path[] = "/map.bin";
// Path to gpx-track file on SD-card
const char gpx_path[] = "/track.gpx";

void setup() {
  sleep(2);
  SPI.setFrequency(SPI_FREQ);
  SPI.begin();
  Serial.begin(9600);

  sout.info() <= "Bike-Companion-32";
  sout.info() << "Build-date: " <= __DATE__;
  
  display.initialize();
  gnss.initialize();
  sdcard.initialize();
  sdcard.setMapPath(binary_path);
  sdcard.setGPXTrackInPath(gpx_path);
  while(!sdcard.readHeader(header)) {
    UIRENDERER.delay(100);
  }
  UIRENDERER.step();
  if(sdcard.readGPX(header, track)) {
    UIRENDERER.setGPXTrackIn(&track);
    BOOTSCREEN.trackOK = true;
  } else {
    // Track could not be initialized. Setup continues.
    BOOTSCREEN.trackOK = -1;
    UIRENDERER.delay(500);
  }
  UIRENDERER.setHeader(&header);
  UIRENDERER.setGNSS(&gnss);
  if(!UIRENDERER.initializeMap(&sdcard)){
    // Map could not be initialized due to insufficient memory. Setup stops.
    BOOTSCREEN.mapOK = -1;
    while(1) {
      UIRENDERER.delay(1000);
    }
  } else {
    BOOTSCREEN.mapOK = true;
  }
  UIRENDERER.setPositionProvider(&ipos);
  
  // Setup was successful. Render some more frames of the bootscreen to show it.
  UIRENDERER.delay(500);

  // Change to map
  UIRENDERER.setScreen(&MAPSCREEN);
}

void loop() {
  // TODO: Handle sudden SD-card removing.

  // double offset1 = 1e-5;
  // double offset2 = 0;
  // currPos.updatePosition(currPos.lat() + offset1, currPos.lon() + offset2);
  // currHeading += 1;
  // currHeading %= 360;
  // mockPosProvider.changePosition(currPos);
  // mockPosProvider.changeHeading(currHeading);

  UIRENDERER.step();

}

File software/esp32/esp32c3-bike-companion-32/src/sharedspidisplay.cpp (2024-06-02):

#include <Arduino.h>

#include <SPI.h>
#include <sharedspidisplay.h>
#include <sharedspimutex.h>
#include <sharedspidevice.h>
#include <screens.h>
#include <uirenderer.h>
#include <serialutils.h>

SharedSPIDisplay::SharedSPIDisplay(uint8_t PIN_CS) : 
    _PIN_CS(PIN_CS), disp(&SPI, PIN_CS, DISPLAY_WIDTH, DISPLAY_HEIGHT, SPI_FREQ), SharedSPIDevice() {

    // Setup chip selector pin
    pinMode(PIN_CS, OUTPUT);
    // Default to disabled (for the sharp display, this means LOW for whatever reason)
    disableCS();

    SMUTEX.registerDevice(this);

};

void SharedSPIDisplay::enableCS() {
    // Serial.print("Device with ID=");
    // Serial.print(device_id);
    // Serial.println(" enabling CS");
    digitalWrite(_PIN_CS, HIGH);
    _hasSPI = true;
};

void SharedSPIDisplay::disableCS() {
    // Serial.print("Device with ID=");
    // Serial.print(device_id);
    // Serial.println(" disabling CS");
    digitalWrite(_PIN_CS, LOW);
    _hasSPI = false;
};

void SharedSPIDisplay::initialize() {
    SMUTEX.aquireSPI(this);
    while(!disp.begin()) {
        delay(100);
        sout.err() <= "Could not find display";
    }
    sout.info() <= "Found display";
    // Update Bootscreen status
    BOOTSCREEN.displayOK = true;
    // Set display and screen for UI renderer
    UIRENDERER.setDisplay(this);
    UIRENDERER.setScreen(&BOOTSCREEN);
}

void SharedSPIDisplay::newPage() {
    SMUTEX.aquireSPI(this);
    clearDisplay();
    disp.setTextSize(1);
    disp.setTextColor(BLACK);
    disp.setCursor(0, 5);
    disp.cp437(true);
}

void SharedSPIDisplay::clearDisplay() { 
    SMUTEX.aquireSPI(this);
    disp.clearDisplay();
}

// Just clear the buffer without rendering. Prevents "flashing"
void SharedSPIDisplay::clearDisplayBuffer() {
    // Does not write anything to the display so
    // we dont need SPI bus access
    disp.clearDisplayBuffer();
}

void SharedSPIDisplay::drawCenterMarker() {
    SMUTEX.aquireSPI(this);
    int16_t x0, y0, x1, y1, x2, y2;
    x0 = DISPLAY_WIDTH_HALF - POSITION_MARKER_SIZE;
    y0 = DISPLAY_WIDTH_HALF + POSITION_MARKER_SIZE;
    x1 = DISPLAY_WIDTH_HALF;
    y1 = DISPLAY_WIDTH_HALF - 2*POSITION_MARKER_SIZE;
    x2 = DISPLAY_WIDTH_HALF + POSITION_MARKER_SIZE;
    y2 = DISPLAY_WIDTH_HALF + POSITION_MARKER_SIZE;
    disp.fillTriangle(x0, y0, x1, y1, x2, y2, BLACK);
};

void SharedSPIDisplay::drawStatusBar(const char* statusStr) {
    SMUTEX.aquireSPI(this);
    disp.fillRect(0, DISPLAY_WIDTH, DISPLAY_WIDTH, DISPLAY_HEIGHT-DISPLAY_WIDTH, WHITE);
    draw_line(0, DISPLAY_WIDTH, DISPLAY_WIDTH, DISPLAY_WIDTH, 4, BLACK);
    disp.setTextSize(2);
    disp.setTextColor(BLACK);
    disp.setCursor(7, DISPLAY_WIDTH+6);
    disp.cp437(true);
    disp.write(statusStr);
};

void SharedSPIDisplay::refresh() {
    SMUTEX.aquireSPI(this);
    disp.refresh();
}

void SharedSPIDisplay::setCursor(int16_t x, int16_t y) {
    // Does not write anything to the display so
    // we dont need SPI bus access
    disp.setCursor(x, y);
}

void SharedSPIDisplay::setTextSize(uint8_t s) {
    // Does not write anything to the display so
    // we dont need SPI bus access
    disp.setTextSize(s);
}

void SharedSPIDisplay::setTextColor(uint16_t c) {
    // Does not write anything to the display so
    // we dont need SPI bus access
    disp.setTextColor(c);
}

void SharedSPIDisplay::drawPixel(int16_t x, int16_t y, uint16_t color) {
    // Does not write anything to the display so
    // we dont need SPI bus access
    disp.drawPixel(x, y, color);
}

void SharedSPIDisplay::fillCircle(int16_t x0, int16_t y0, int16_t r, uint16_t color) {
    SMUTEX.aquireSPI(this);
    disp.fillCircle(x0, y0, r, color);
}

void SharedSPIDisplay::drawQuaterCircle(int16_t x0, int16_t y0, int16_t r, uint8_t cornername, uint16_t color) {
    disp.drawCircleHelper(x0, y0, r, cornername, color);
};

void SharedSPIDisplay::write(const char* str, bool hold) {
    disp.setTextColor(BLACK);
    disp.write(str);
    if(!hold) {
        SMUTEX.aquireSPI(this);
        disp.refresh();
    }
}

void SharedSPIDisplay::draw_line(int x0, int y0, int x1, int y1, uint8_t thickness, uint16_t color) {
    // Does not write anything to the display so
    // we dont need SPI bus access
    int dx =  abs(x1 - x0), sx = x0 < x1 ? 1 : -1;
    int dy = -abs(y1 - y0), sy = y0 < y1 ? 1 : -1;
    int err = dx + dy, e2;

    if(dx < -dy) {
        while (1) {
        disp.drawPixel(x0, y0, color);
        for(int i=0; i<thickness-1; i++) {
            disp.drawPixel(x0+thickness_offsets[i], y0, color);
        }
        if (x0 == x1 && y0 == y1) break;
        e2 = 2 * err;
        if (e2 > dy) { err += dy; x0 += sx; }
        if (e2 < dx) { err += dx; y0 += sy; }
        }
    } else {
        while (1) {
        disp.drawPixel(x0, y0, color);
        for(int i=0; i<thickness-1; i++) {
            disp.drawPixel(x0, y0+thickness_offsets[i], color);
        }
        if (x0 == x1 && y0 == y1) break;
        e2 = 2 * err;
        if (e2 > dy) { err += dy; x0 += sx; }
        if (e2 < dx) { err += dx; y0 += sy; }
        }
    }

}


void SharedSPIDisplay::draw_dashedline(int x0, int y0, int x1, int y1, uint8_t thickness, uint8_t dashLength, uint16_t color) {
    // Does not write anything to the display so
    // we dont need SPI bus access
    int dx =  abs(x1 - x0), sx = x0 < x1 ? 1 : -1;
    int dy = -abs(y1 - y0), sy = y0 < y1 ? 1 : -1;
    int err = dx + dy, e2;

    uint8_t cnt = 0;

    if(dx < -dy) {
        while (1) {
        ++cnt %= dashLength;
        if(!cnt) color = !color;

        disp.drawPixel(x0, y0, color);
        for(int i=0; i<thickness-1; i++) {
            disp.drawPixel(x0+thickness_offsets[i], y0, color);
        }
        if (x0 == x1 && y0 == y1) break;
        e2 = 2 * err;
        if (e2 > dy) { err += dy; x0 += sx; }
        if (e2 < dx) { err += dx; y0 += sy; }
        }
    } else {
        while (1) {
        ++cnt %= dashLength;
        if(!cnt) color = !color;

        disp.drawPixel(x0, y0, color);
        for(int i=0; i<thickness-1; i++) {
            disp.drawPixel(x0, y0+thickness_offsets[i], color);
        }
        if (x0 == x1 && y0 == y1) break;
        e2 = 2 * err;
        if (e2 > dy) { err += dy; x0 += sx; }
        if (e2 < dx) { err += dx; y0 += sy; }
        }
    }

}

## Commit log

2023-12-03 migration to github
    [BOM-Companion.xlsx, Bike-Companion-32.step, BikeMountLower v1.stl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]
2023-12-03 fixed wiring diagram
2024-04-20 fixes for signed mercator coordinates
    [BoundingBox.hpp, main.cpp]
2024-06-03 added signed tile origins, fix for long node distances, fixed typo in python utilities
    [BoundingBox.hpp]
